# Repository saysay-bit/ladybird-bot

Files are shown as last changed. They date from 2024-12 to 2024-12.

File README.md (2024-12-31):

**Drawings**: Engineering drawings of individual parts

**Extra Components**: 3D models of extra components, e.g. spacers and nuts (not original)

**Main Parts**: 3D models of individual parts (.ipt)

**STL files**: 3D models of individual parts (.stl)

**LadybugBot Code.ino**: Full robot code for Arduino

**Robot Presentation Slides**: Presentation slides (for assessment) - can also be used as a summary

**robot.h**: Robot library

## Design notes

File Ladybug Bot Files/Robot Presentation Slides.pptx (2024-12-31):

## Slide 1

I Maze Solving Robot I
Ladybug Bot

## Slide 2

I Chassis Construction I
I Design & Creation I

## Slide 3

Design - Base

- Designed with the ladybug concept in mind
  - Large “body” section - ARB board, battery pack
  - Smaller “head” section - ball caster is mounted in direct centre
- Ultrasonic sensors
  - One at direct front, and one on each side
- Battery pack slots
  - Four rectangular slots in the centre
  - Battery pack stand slots in & out (keyhole)

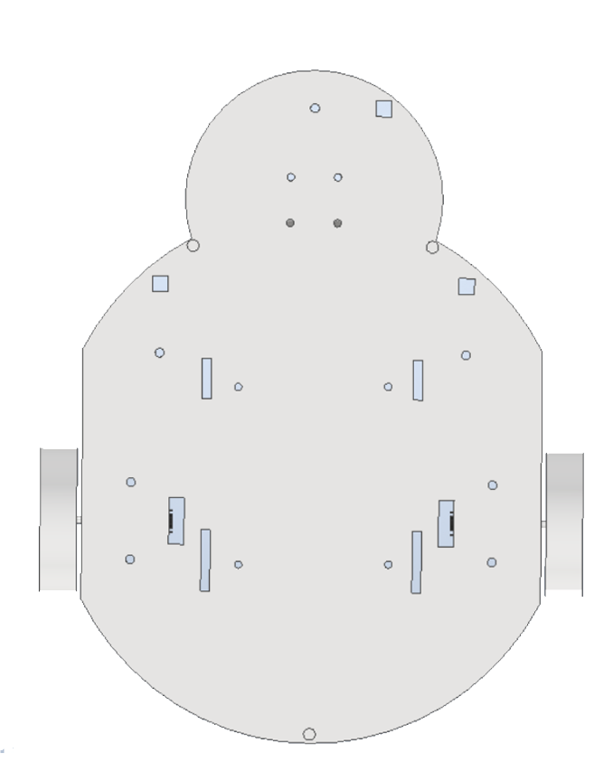
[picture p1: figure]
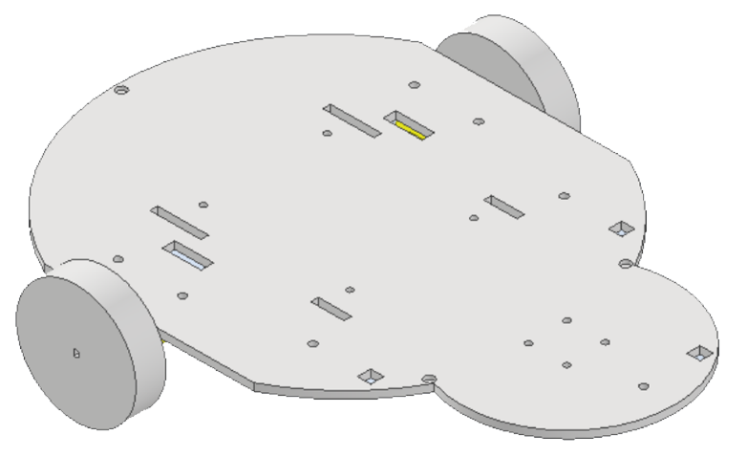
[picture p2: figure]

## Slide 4

Design - Battery Pack

- A stand that slots through the keyholes and rests above the ARB board.
- Small layer of foam to protect the battery pack and allow it to be removed in and out.
- Rounded slots on top to increase safety during use
- Printed in red to stick with the ladybug theme.

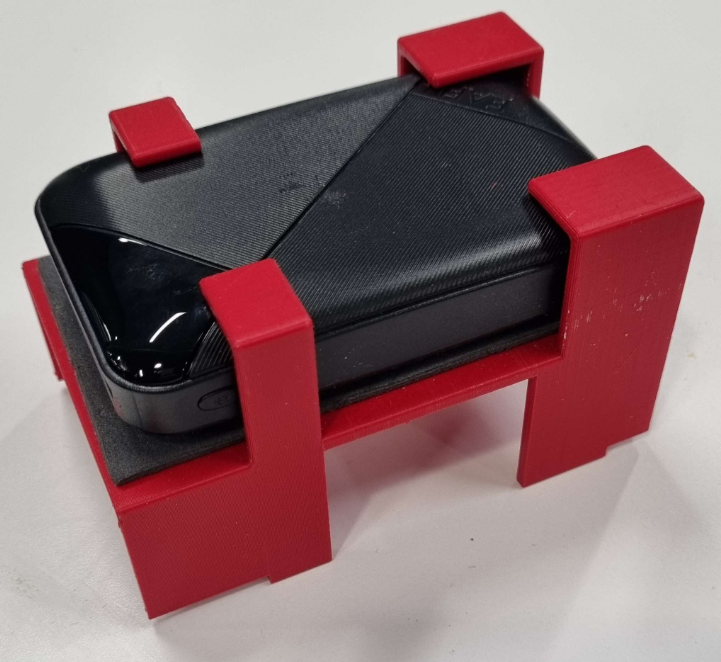
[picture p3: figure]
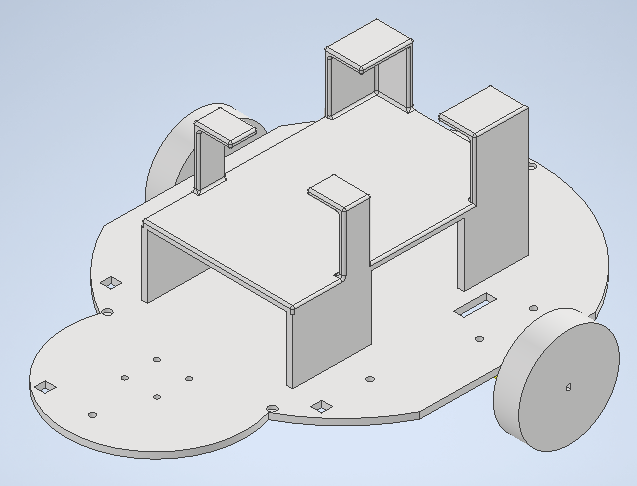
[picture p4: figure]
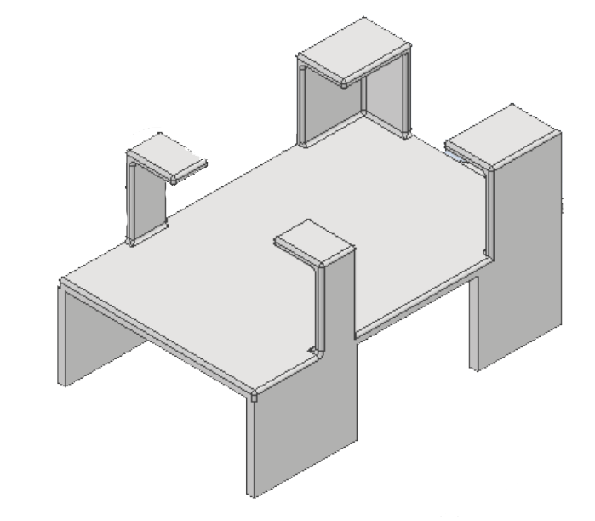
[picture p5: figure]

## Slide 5

Design - Cover

- Ladybug themed outer case, originally printed in black - spray painted red and small dots drawn on
- Magnetic holes on edges to stick neatly onto base
- Holes on sides and front to allow space for sensors
- Also doubles as protection for electronic parts
- Makes the Ladybug bot actually a ladybug!

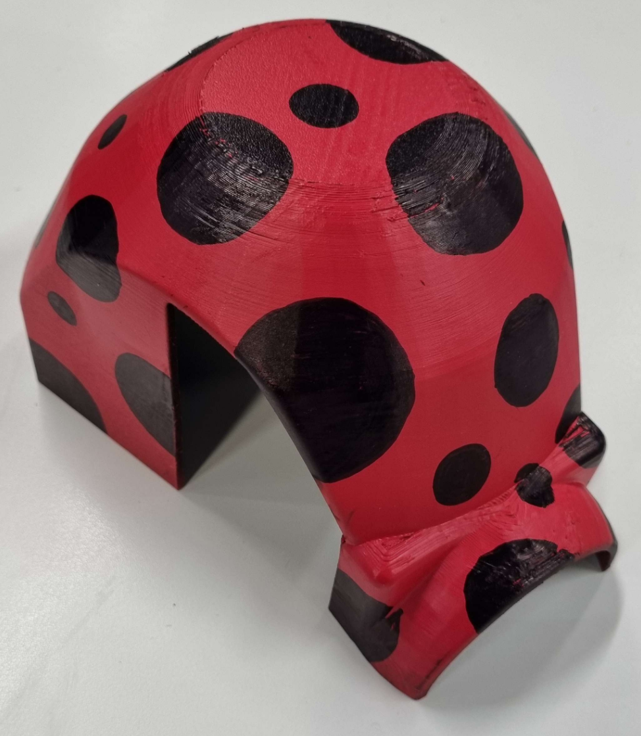
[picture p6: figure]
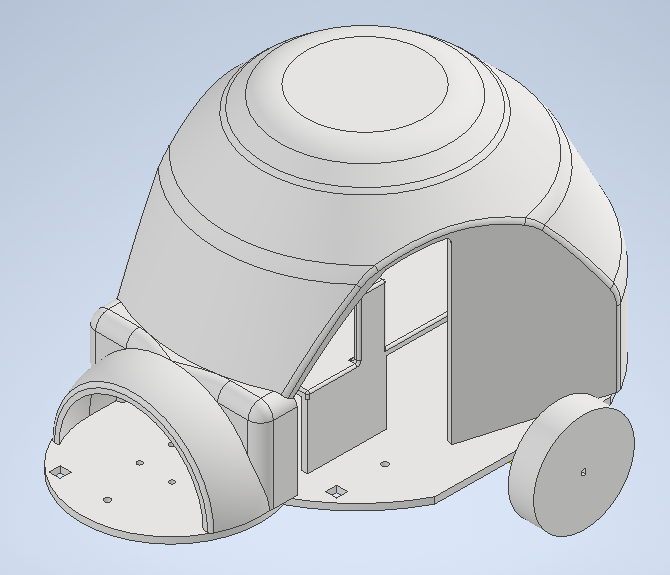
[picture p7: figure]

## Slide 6

I Obstacle Detection & Avoidance I
I Coding, Coordinates, Obstacles I

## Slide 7

Obstacle Detection - Sensors & Coordinates

- The Ladybug can sense obstacles around it using its ultrasonic sensors
- When the sensors detect something within <10 cm range:
  - Obstacle detected!
- Sensor readings are stored in a struct
- All sensors can be read at once and don’t need to be called individually!
- Once the obstacle is detected, the Ladybug can “map” it
- Coordinates of the obstacle are determined accordingly based on:
  - Distance to the obstacle, gathered from the sensors
  - Current location of the Ladybug

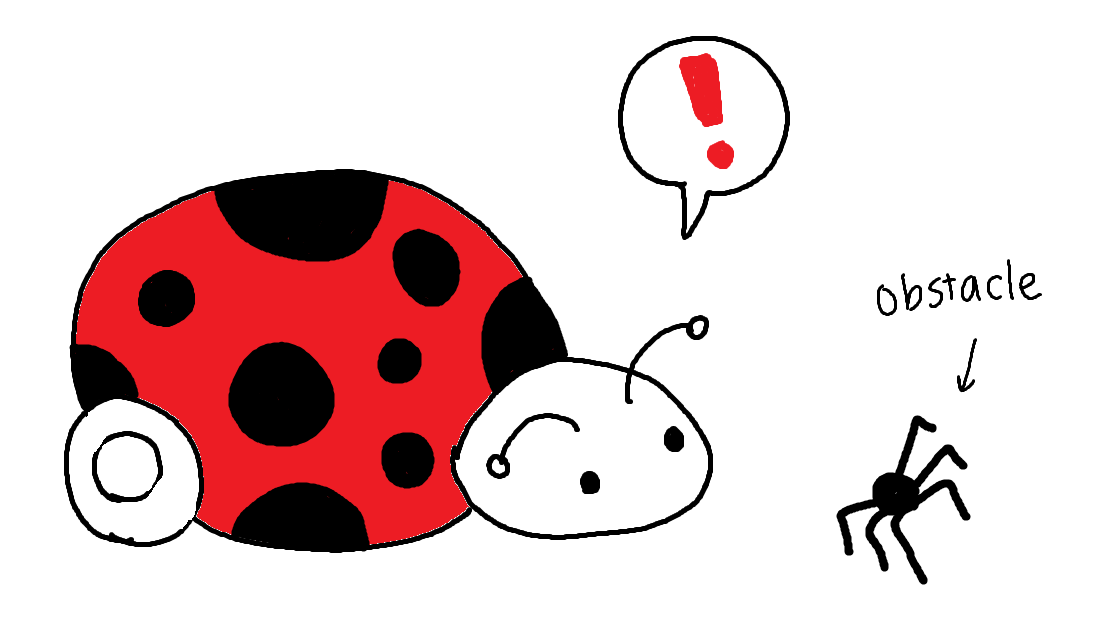
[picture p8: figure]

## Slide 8

Obstacle Detection - Movement

- The Ladybug can be programmed to avoid obstacles once detected!
- Forward/backward movement commands can be issued with two inputs:
  - Speed (in cm per second)
  - Target distance (in cm)
- The Ladybug will move at the input speed until the target distance is reached.
- Turn commands can be issued with two inputs:
  - Speed (in cm per second)
  - Target angle displacement (in degrees)
- All movements are set to a default speed of 8 cm/s
- Default turns are 90 degrees

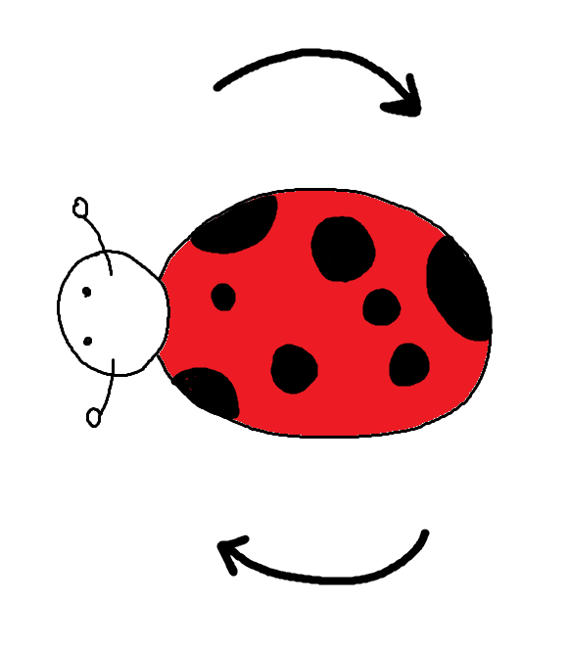
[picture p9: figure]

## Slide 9

I Maze Solutions I
I Shortest Path and Dijkstra’s Algorithm I

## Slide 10

Maze Solutions - Occupancy Grids

- The Ladybug creates an occupancy grid of the map that gets updated with obstacles as it moves.
- Each “cell” in the grid is 17cm x 17cm, and this creates a coordinate system.
- The occupancy grid is printed with (in testing):
  - Start (S)
  - Goal (G)
  - Path cells (*)
  - Obstacle (#)
  - Regular cells (.)
- But for simplicity is printed with 1s and 2s.

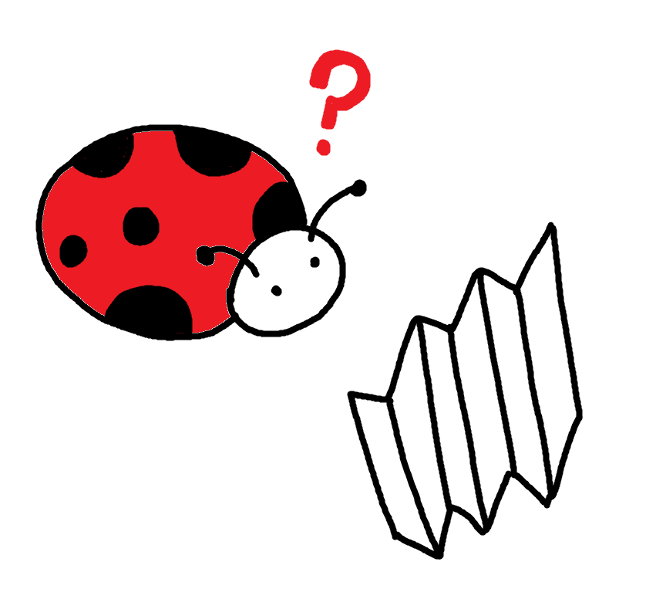
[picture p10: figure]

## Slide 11

Maze Solutions - Dijkstra’s Algorithm

- The Ladybug uses Dijkstra’s algorithm to compute the shortest path to the goal from the current point.
- As obstacles are mapped out, the new path is computed considering the obstacles.
- At the end, the Ladybug receives the shortest path to the goal as an array of coordinates.
- It also receives the length of the shortest path (in steps).
- In testing, the dijkstra() function can:
  - Print out a small map with the shortest path marked;
  - Print out the route as steps of coordinates.
- Once the ladybug receives the path:
  - It will attempt to follow each coordinate step by step.
  - Once the new coordinate is reached:
    - Obstacles are sensed and added onto the map.
    - Dijkstra runs again and returns a new path
    - Process repeats until goal is reached!

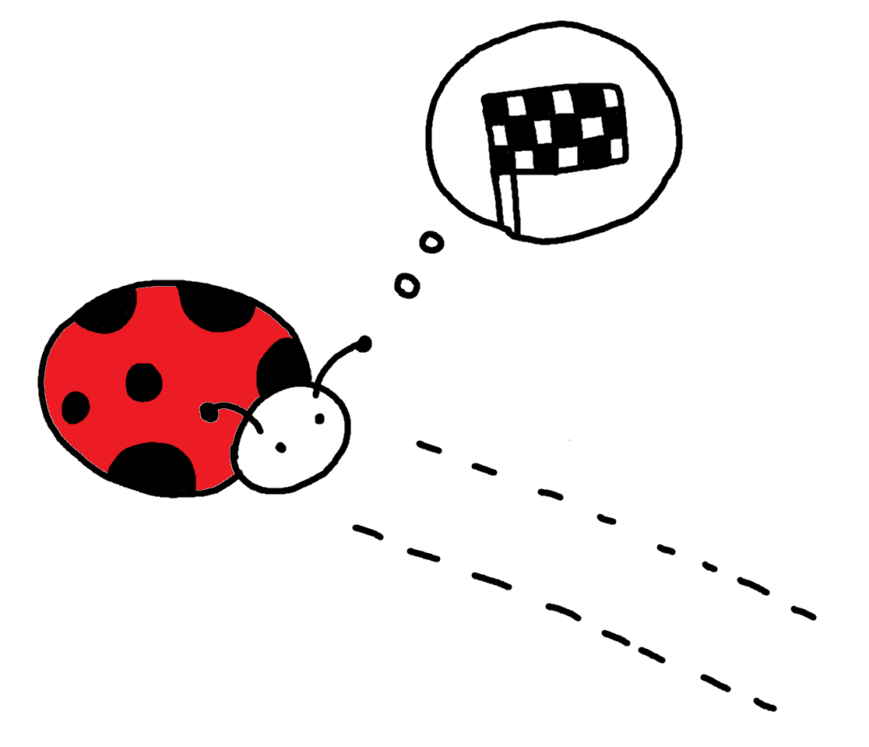
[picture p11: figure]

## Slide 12

Maze Solutions - Backtracking

- Once the goal is met, the Ladybug will reset its goal back to (0,0) - the start
- It will rerun the algorithms until it reaches its new goal - the start!
- The maze is then solved via Dijkstra’s!

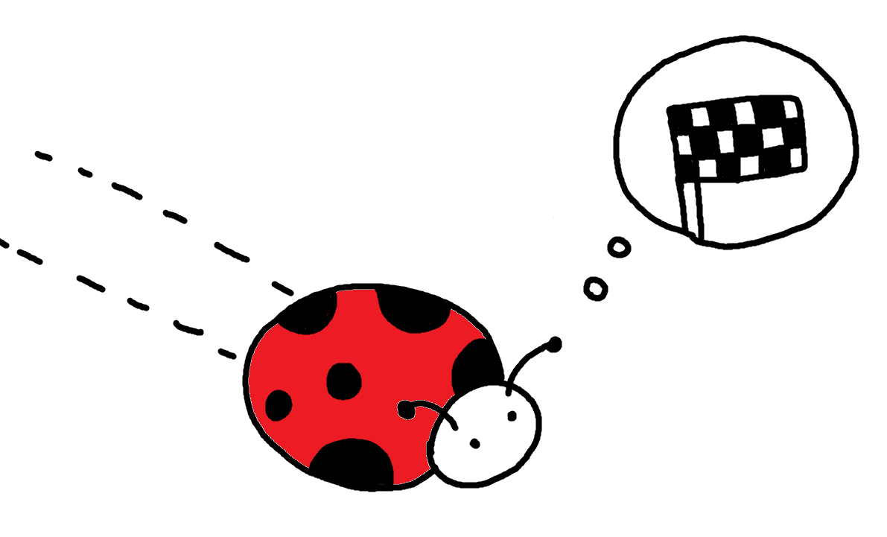
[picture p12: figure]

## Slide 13

I Bugsquashing I
I Problem Troubleshooting I

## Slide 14

Bug-squashing

- Bugs were fixed via repeated trial and error, and lots of print() statements!
- Threading was used to optimise angle & distance calculations
  - They depended on the encoders
  - Running them in tandem with everything else increased efficiency
- On initial submission, the Ladybug was able to find a path and update the map with obstacles, but struggled to follow the path properly.
  - This was (hopefully) fixed for the final presentation to ensure a smooth demonstration

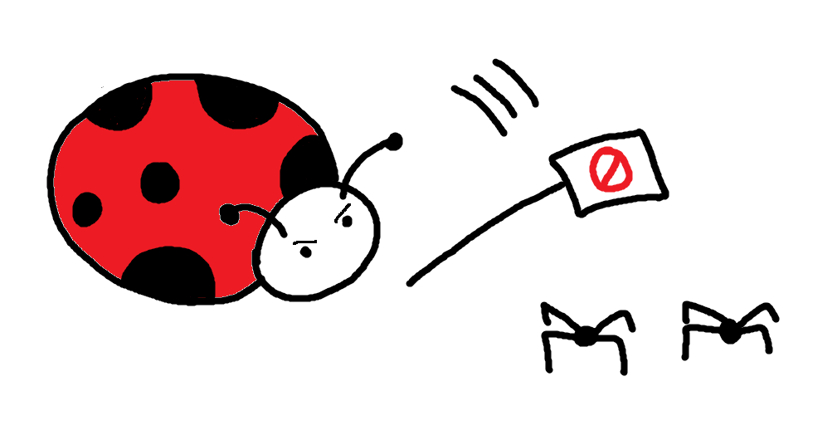
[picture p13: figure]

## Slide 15

I Improvements & Evaluation I
I What could’ve gone better? I

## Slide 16

I Thank you! I
I Any Questions? I

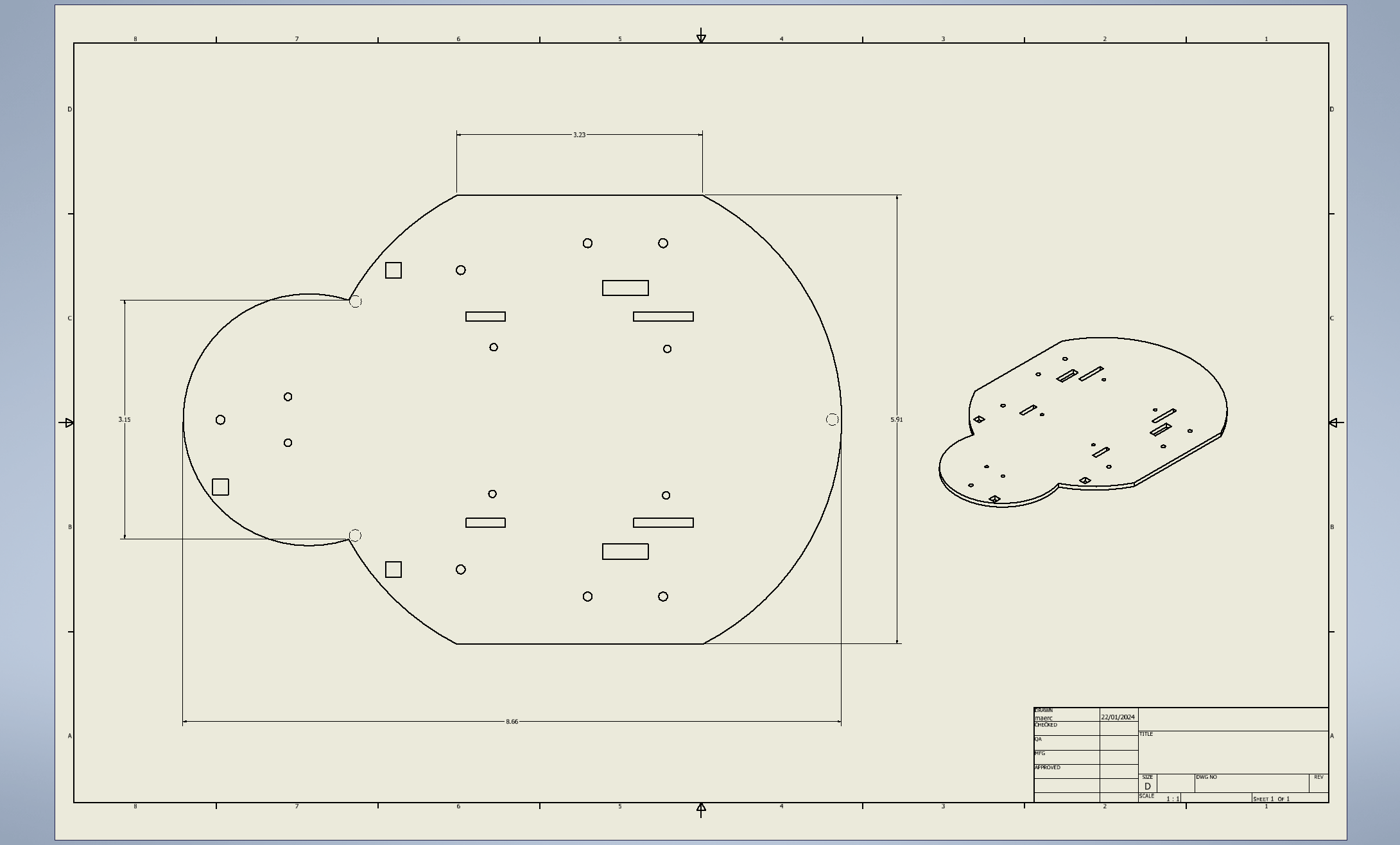
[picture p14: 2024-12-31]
Ladybug Bot Files/Drawings/Copy of Base Drawing.png

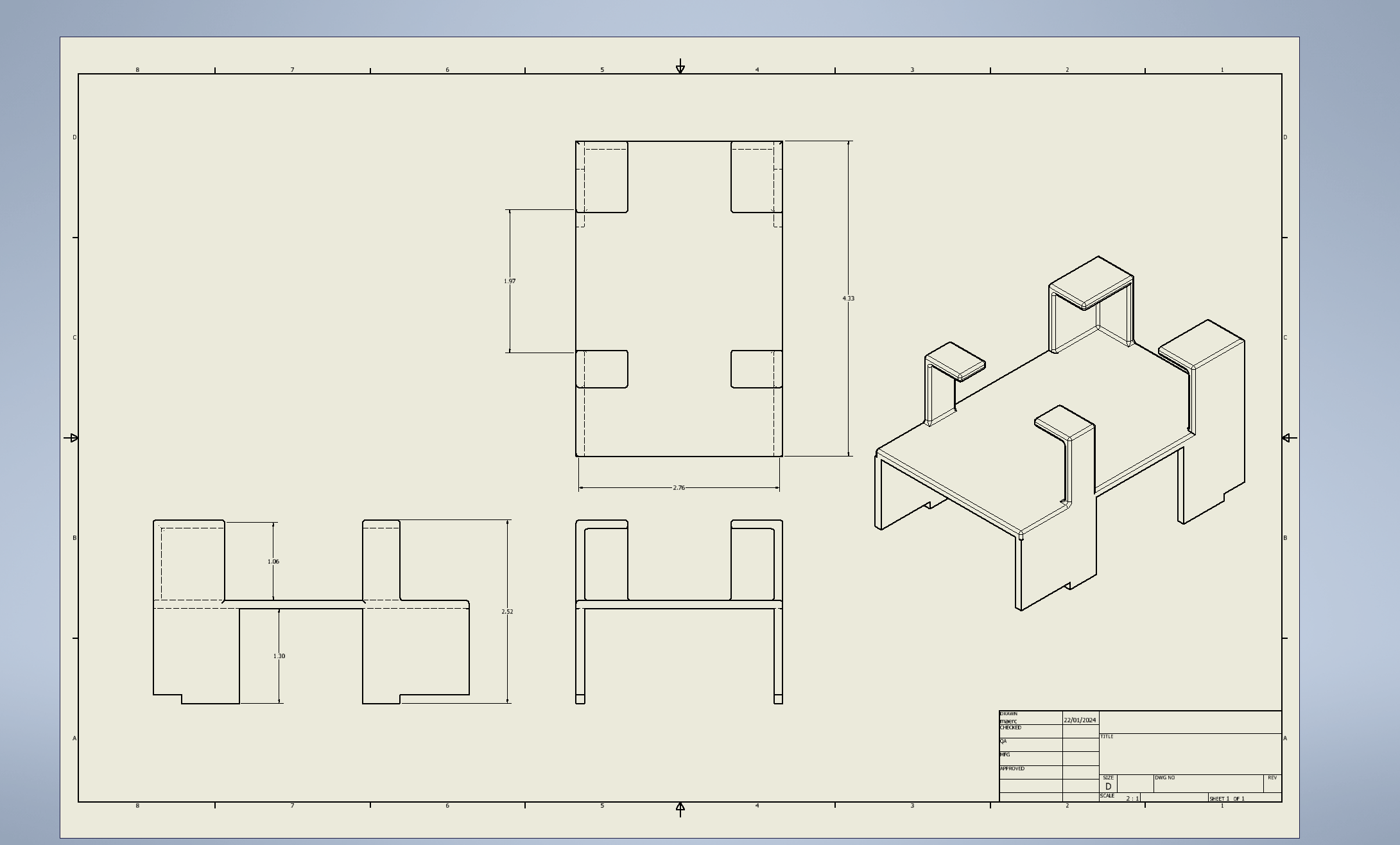
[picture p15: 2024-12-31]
Ladybug Bot Files/Drawings/Copy of Battery Holder Drawing.png

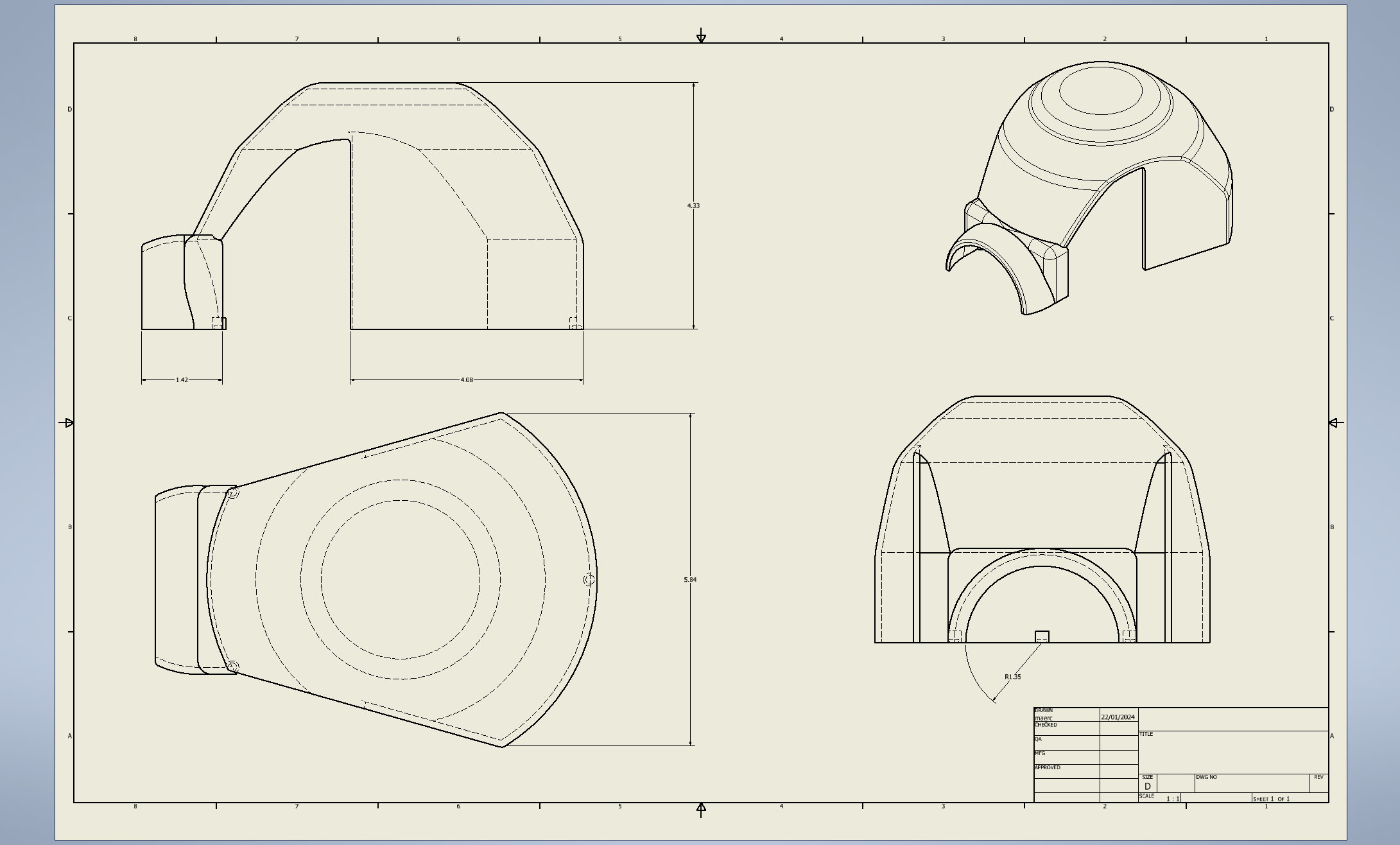
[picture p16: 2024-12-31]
Ladybug Bot Files/Drawings/Copy of Outer Cover Drawing.png

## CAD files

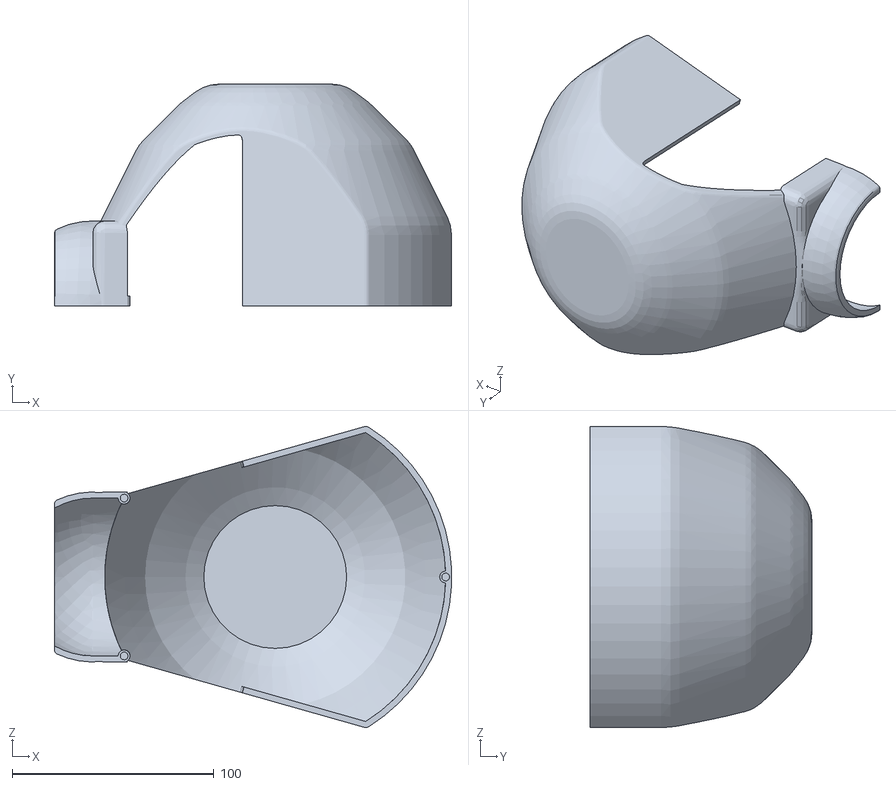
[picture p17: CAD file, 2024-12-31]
Ladybug Bot Files/STL files/BodyCover.stl
196.8 x 110.0 x 149.2

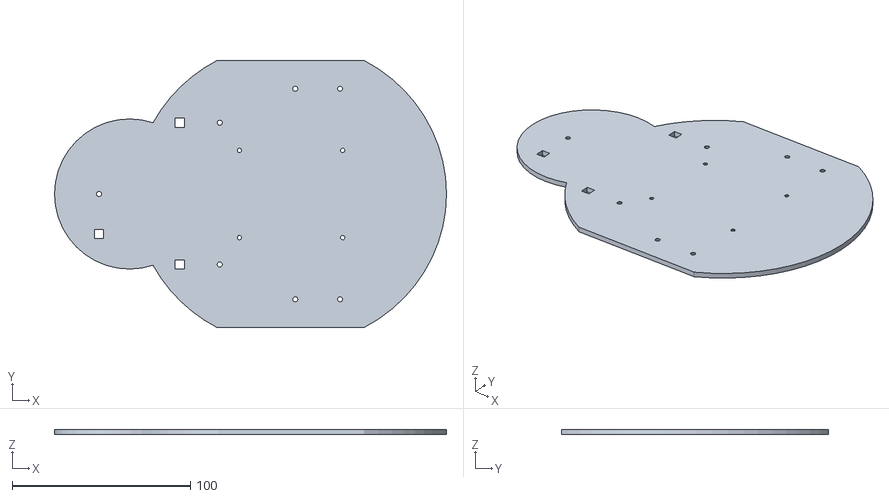
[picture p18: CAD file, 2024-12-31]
Ladybug Bot Files/STL files/Base.stl
220.0 x 150.1 x 3.00

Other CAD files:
Ladybug Bot Files/Extra Components (e.g. Spacers-Nuts)/Copy of 0.75in Ball Caster (Pololu).ipt
Ladybug Bot Files/Extra Components (e.g. Spacers-Nuts)/Copy of Caster Spacer 1,7mm.ipt
Ladybug Bot Files/Extra Components (e.g. Spacers-Nuts)/Copy of Caster Spacer 3,1mm.ipt
Ladybug Bot Files/Extra Components (e.g. Spacers-Nuts)/Copy of Caster Spacer 3mm.ipt
Ladybug Bot Files/Extra Components (e.g. Spacers-Nuts)/Copy of Caster Spacer 5mm.ipt
Ladybug Bot Files/Extra Components (e.g. Spacers-Nuts)/Copy of HC-SR04-UltrasonicSensor v7.ipt
Ladybug Bot Files/Extra Components (e.g. Spacers-Nuts)/Copy of M2.5 Hex Spacer 5mm.ipt
Ladybug Bot Files/Extra Components (e.g. Spacers-Nuts)/Copy of Motor Mount.ipt
Ladybug Bot Files/Extra Components (e.g. Spacers-Nuts)/Copy of MotorHolder.ipt
Ladybug Bot Files/Extra Components (e.g. Spacers-Nuts)/Copy of Motors Full Assembly.iam
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

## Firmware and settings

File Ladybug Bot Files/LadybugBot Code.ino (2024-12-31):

#include "mbed.h"
#include "robot.h"
using namespace rtos;
using namespace mbed;

#define PWM_PIN_A P0_27
#define PWM_PIN_B P1_2
#define DIR_PIN_A P0_4
#define DIR_PIN_B P0_5

#define ENC_PIN_A P1_11
#define ENC_PIN_B P1_12

#define SENSORLEFT_PIN 6   //P1_14 - SENSOR 2
#define SENSORFRONT_PIN 7  //P0_23 - SENSOR 1
#define SENSORRIGHT_PIN 4  //P1_15 - SENSOR 4

mbed::PwmOut MotorAPWM(P0_27);
mbed::PwmOut MotorBPWM(P1_2);

mbed::DigitalOut MotorADir(P0_4);
mbed::DigitalOut MotorBDir(P0_5);

Motor MotorA(PWM_PIN_A, DIR_PIN_A);
Motor MotorB(PWM_PIN_B, DIR_PIN_B);

UltrasonicSensor sensor_left(SENSORLEFT_PIN);
UltrasonicSensor sensor_front(SENSORFRONT_PIN);
UltrasonicSensor sensor_right(SENSORRIGHT_PIN);

float speedDefault = 8;
float distanceDefault = 10;
float turnDefault = 90;

int MovingCoords = 0;

int XMovement = 0;
int YMovement = 0;

int lastCoordsX = 0;
int lastCoordsY = 0;

int x_movement = 0;
int y_movement = 0;

char TargetFacing = 'U';
char Facing = 'U';

// Define grid dimensions
#define GRID_ROWS 12  //one grid box would be 17x17 cm
#define GRID_COLS 9
#define INT_MAX 100

// Define the occupancy grid
int MazeMap[GRID_ROWS][GRID_COLS] = {};

struct Cell {
  int CellX, CellY;
};

int CoordsX = 0;
int CoordsY = 0;

bool MovingDirection = true;

bool ObstacleLeft = false;
bool ObstacleRight = false;
bool ObstacleFront = false;

struct Cell start = { CoordsX, CoordsY };
struct Cell goal = { 4, 4 };

struct Cell path[GRID_ROWS * GRID_COLS];
int pathLength = 0;


//=======================================================================================================================================================================================
//State variables for localization: add each update and never set to 0
float angle = 90;  //0 is along the x-axis (unit circle)
float positionX = 0;
float positionY = 0;

Thread angleChecking;

//Sensor Readings structure and function===================================================================================================================================================
struct SensorReadings {  //group related data items under a single name
  float distance_left;
  float distance_front;
  float distance_right;
};


SensorReadings readAllSensors() {  //returns an instance of SensorReadings structure
  SensorReadings readings;
  readings.distance_left = sensor_left.DistanceMeasurement();
  readings.distance_front = sensor_front.DistanceMeasurement();
  readings.distance_right = sensor_right.DistanceMeasurement();

  return readings;
}



//Robot current state: updated by state functions ===============================================================================================================================
enum robotState { stopState = 0,
                  forwardState,
                  leftState,
                  rightState,
                  backState,
                  defaultState
} behaviour;


//===============================================================================================================================================================================
//Behavior variables: updated in each loop but only reset once behavior finishes (e.g. move x cm)
float distanceMoved = 0.0;
float angleMoved = 0.0;

float distanceRTotal = 0.0;
float distanceLTotal = 0.0;

//angle fixing to 90 ================================================================================================================================================


bool ActionComplete = false;

//moving forward/backward/turning ================================================================================================================================================
void move(float speedIn, float targetDistance, bool moveBack) {
  angleChecking.start(callback(anglesAndCoordsUpdate));

  updateMazeMapObstacles();


  //positionFixing.start(callback(fix_position));

  ActionComplete = false;

  float speedOut = (speedIn + 3) / 40;

  MotorAPWM.write(speedOut);
  MotorBPWM.write(speedOut);
  MotorADir = moveBack ? 0 : 1;
  MotorBDir = moveBack ? 1 : 0;


  float tolerance = 1;  //note distances to actual distances are 1cm off, but tolerance is low to avoid error

  //ISSUE WITH MOVEMENT ADDING 2 TO COORDS SEEMS TO BE HERE, FIXED BY CHECKING COORDINATE NOT DISTANCE

  static float initialDistance = ((std::fabs(distanceRTotal) + std::fabs(distanceLTotal)) * 0.5);
  float currentDistance = ((std::fabs(distanceRTotal) + std::fabs(distanceLTotal)) * 0.5);

  float adjusted_targetDistance = (moveBack ? -targetDistance : targetDistance);
  if (MovingCoords == 1) {
    if (Facing == 'L' || Facing == 'R') {
      if (CoordsX == XMovement) {
        stop();
        ActionComplete = true;
        Serial.println("Distance Met!");
        initialDistance = (std::fabs(distanceRTotal) + std::fabs(distanceLTotal)) / 2;
      }
    } else {
      if (Facing == 'F' || Facing == 'B') {
        if (CoordsY == YMovement) {
          stop();
          ActionComplete = true;
          Serial.println("Distance Met!");
          initialDistance = (std::fabs(distanceRTotal) + std::fabs(distanceLTotal)) / 2;
        }
      } else {
        Serial.println("Unknown Movement Direction!");
      }
    }
  } else {
    if ((std::fabs(initialDistance - currentDistance + adjusted_targetDistance)) <= tolerance) {
      stop();
      ActionComplete = true;
      Serial.println("Distance Met!");
      initialDistance = (std::fabs(distanceRTotal) + std::fabs(distanceLTotal)) / 2;
    }
  }
}


void move_forward(float speedIn, float targetDistance) {
  while (ActionComplete == false) {
    move(speedIn, targetDistance, false);
  }
}

void move_backward(float speedIn, float targetDistance) {
  while (ActionComplete == false) {

    move(speedIn, targetDistance, true);
  }
}

void testing_function() {
  static int testState = 0;

  switch (testState) {
    case 0:
      moveToCoords(2, 2);
      break;
  }
}

void stop() {
  MotorAPWM.write(0);
  MotorBPWM.write(0);
}

static float initialAngle = angle;
static int fullRotations = 0;
float prevDeltaX = 0;
float prevDeltaY = 0;
float cumulativeX = 0;
float cumulativeY = 0;

void turn(float speedIn, float targetAngle, bool turnRight) {
  //Serial.println("Turning");
  angleChecking.start(callback(anglesAndCoordsUpdate));
  ActionComplete = false;

  static float initialAngle = angle;

  float speedOut = (speedIn + 3) / 40;
  MotorAPWM.write(speedOut);
  MotorBPWM.write(speedOut);
  MotorADir = turnRight ? 0 : 1;
  MotorBDir = turnRight ? 0 : 1;

  float tolerance = 1.0;

  if (turnRight) {  //math for turning right
    if (initialAngle < -270) {
      if (std::fabs(angle - 360.0f - initialAngle + targetAngle) <= tolerance) {
        //behaviour = forwardState; //change to stop for testing
        stop();
        angleMoved = 0;
        initialAngle = angle;
        ActionComplete = true;
        wait_us(1000);
      }
    } else {
      if (std::fabs(angle - 0 - initialAngle + targetAngle) <= tolerance) {  //fullRotations to 0
        //behaviour = forwardState; //change to stop for testing
        stop();
        angleMoved = 0;
        initialAngle = angle;
        ActionComplete = true;
        wait_us(1000);
      }
    }
  } else {  //math for turning left
    if (initialAngle > 270) {
      if (std::fabs(angle + 360.0f - initialAngle - targetAngle) <= tolerance) {
        //behaviour = forwardState; //change to stop for testing
        stop();
        angleMoved = 0;
        initialAngle = angle;
        ActionComplete = true;
        wait_us(1000);
      }
    } else {
      if (std::fabs(angle + 0 - initialAngle - targetAngle) <= tolerance) {  //fullRotations to 0
        //behaviour = forwardState; //change to stop for testing
        stop();
        angleMoved = 0;
        initialAngle = angle;
        ActionComplete = true;
        wait_us(1000);
      }
    }
  }


  wait_us(10000);  // Adjust the delay as needed
}

void turn_right(float speedIn, float targetAngle) {
  Serial.println("Turning Right");
  while (ActionComplete == false) {
    turn(speedIn, targetAngle, true);
  }
}


void turn_left(float speedIn, float targetAngle) {
  Serial.println("Turning Left");
  while (ActionComplete == false) {
    turn(speedIn, targetAngle, false);
  }
}


//defining interrupts and timers to count encoders===========================================================================================================================
mbed::InterruptIn EncoderR(P1_11);
mbed::InterruptIn EncoderL(P1_12);

long int WheelRevR;
long int WheelRevL;

long int PulseCountR;
long int PulseCountL;

mbed::Timer timeCheck;



//encoder count read functions =======================================================================================================================================================
void countEncoderR() {
  PulseCountR++;  //encoder count increases on every rising edge (0 to 1)

  if (PulseCountR % 6 == 0) {      //checks if one rotation has completed (6 counts per rotation)
    if (PulseCountR % 100 == 0) {  //increases Shaft Revolutions every 100 counts
      WheelRevR++;
    }
  }
}

void countEncoderL() {
  PulseCountL++;  //encoder count increases on every rising edge (0 to 1)

  if (PulseCountL % 6 == 0) {      //checks if one rotation has completed (6 counts per rotation)
    if (PulseCountL % 100 == 0) {  //increases Shaft Revolutions every 100 counts
      WheelRevL++;
    }
  }
}


//Map stuff =========================================================================================================================================================================
void printMazeMap() {
  for (int i = 0; i < GRID_ROWS; i++) {
    for (int j = 0; j < GRID_COLS; j++) {
      Serial.print(MazeMap[i][j]);
      Serial.print(" ");
    }
    Serial.println();
  }
}

void initialiseMazeMap() {
  for (int i = 0; i < GRID_ROWS; ++i) {
    for (int j = 0; j < GRID_COLS; ++j) {
      MazeMap[i][j] = 1;
    }
  }
}

int ObstacleX;
int ObstacleY;


void ObstacleMapping() {
  CoordsX = CoordsX;
  CoordsY = CoordsY;
  findFacing();

  Serial.println(Facing);
  SensorReadings currentReadings = readAllSensors();

  if (ObstacleLeft == true) {
    if (Facing == 'F') {
      Serial.println("Facing F");
      ObstacleX = CoordsX - 1;
      ObstacleY = CoordsY;
      MazeMap[ObstacleX][ObstacleY] = 2;

    } else if (Facing == 'B') {
      Serial.println("Facing B");
      ObstacleX = CoordsX + 1;
      ObstacleY = CoordsY;
      MazeMap[ObstacleX][ObstacleY] = 2;

    } else if (Facing == 'R') {
      Serial.println("Facing R");
      ObstacleX = CoordsX;
      ObstacleY = CoordsY + 1;
      MazeMap[ObstacleX][ObstacleY] = 2;

    } else if (Facing == 'L') {
      Serial.println("Facing L");
      ObstacleX = CoordsX;
      ObstacleY = CoordsY - 1;
      MazeMap[ObstacleX][ObstacleY] = 2;
    }
    Serial.print("CoordsX: ");
    Serial.println(CoordsX);
    Serial.print("CoordsY: ");
    Serial.println(CoordsY);
    Serial.println("Obstacle to the left`!");
    Serial.print("Obstacle X: ");
    Serial.println(ObstacleX);
    Serial.print("Obstacle Y: ");
    Serial.println(ObstacleY);

    ObstacleLeft = false;
  }
  if (ObstacleRight == true) {
    if (Facing == 'F') {
      Serial.println("Facing F");
      ObstacleX = CoordsX + 1;
      ObstacleY = CoordsY;
      MazeMap[ObstacleX][ObstacleY] = 2;

    } else if (Facing == 'B') {
      Serial.println("Facing B");
      ObstacleX = CoordsX - 1;
      ObstacleY = CoordsY;
      MazeMap[ObstacleX][ObstacleY] = 2;

    } else if (Facing == 'R') {
      Serial.println("Facing R");
      ObstacleX = CoordsX;
      ObstacleY = CoordsY - 1;
      MazeMap[ObstacleX][ObstacleY] = 2;

    } else if (Facing == 'L') {
      Serial.println("Facing L");
      ObstacleX = CoordsX;
      ObstacleY = CoordsY + 1;
      MazeMap[ObstacleX][ObstacleY] = 2;
    }

    Serial.print("CoordsX: ");
    Serial.println(CoordsX);
    Serial.print("CoordsY: ");
    Serial.println(CoordsY);
    Serial.println("Obstacle to the right!");
    Serial.print("Obstacle X: ");
    Serial.println(ObstacleX);
    Serial.print("Obstacle Y: ");
    Serial.println(ObstacleY);
    ObstacleRight = false;
  }
  if (ObstacleFront == true) {
    if (Facing == 'F') {
      Serial.println("Facing F");
      ObstacleX = CoordsX;
      ObstacleY = CoordsY + 1;
      MazeMap[ObstacleX][ObstacleY] = 2;

    } else if (Facing == 'B') {
      Serial.println("Facing B");
      ObstacleX = CoordsX;
      ObstacleY = CoordsY - 1;
      MazeMap[ObstacleX][ObstacleY] = 2;

    } else if (Facing == 'R') {

      Serial.println("Facing R");
      ObstacleX = CoordsX + 1;
      ObstacleY = CoordsY;
      MazeMap[ObstacleX][ObstacleY] = 2;

    } else if (Facing == 'L') {
      Serial.println("Facing L");
      ObstacleX = CoordsX - 1;
      ObstacleY = CoordsY;
      MazeMap[ObstacleX][ObstacleY] = 2;
    }
    ObstacleFront = false;
    Serial.print("CoordsX: ");
    Serial.println(CoordsX);
    Serial.print("CoordsY: ");
    Serial.println(CoordsY);
    Serial.println("Obstacle ahead!");
    Serial.print("Obstacle X: ");
    Serial.println(ObstacleX);
    Serial.print("Obstacle Y: ");
    Serial.println(ObstacleY);
  }
}

void updateMazeMapObstacles() {
  angleChecking.start(callback(anglesAndCoordsUpdate));
  SensorReadings currentReadings = readAllSensors();
  if (currentReadings.distance_left < 8 && currentReadings.distance_left > 0) {

    ObstacleLeft = true;
    Serial.println("OBSTACLE LEFT");
  }

  if (currentReadings.distance_right < 8 && currentReadings.distance_right > 0) {

    ObstacleRight = true;
    Serial.println("OBSTACLE RIGHT");
  }

  if (currentReadings.distance_front < 8 && currentReadings.distance_front > 0) {

    ObstacleFront = true;
    Serial.println("OBSTACLE FRONT");
  }

  //MazeMap[ObstacleX][ObstacleY] = 2;  //assigns the grid with these coordinates with a 1
  dijkstra(MazeMap, start, goal);
  Serial.println("Occupancy Grid:");
  printMazeMap();
}

//Dijkstra stuff ===================================================================================================================================================================================

int isValid(int row, int col) {
  return (row >= 0) && (row < GRID_ROWS) && (col >= 0) && (col < GRID_COLS);
}

int min(int a, int b) {
  return (a < b) ? a : b;
}

int dijkstra(int maze[GRID_ROWS][GRID_COLS], struct Cell begin, struct Cell goal) {
  begin = { CoordsX, CoordsY };

  angleChecking.start(callback(anglesAndCoordsUpdate));
  pathLength = 0;  // Reset pathLength

  // defining stuff
  int distances[GRID_ROWS][GRID_COLS];
  int visited[GRID_ROWS][GRID_COLS];
  struct Cell predecessors[GRID_ROWS][GRID_COLS];

  for (int i = 0; i < GRID_ROWS; i++) {
    for (int j = 0; j < GRID_COLS; j++) {
      distances[i][j] = INT_MAX;
      visited[i][j] = 0;
      predecessors[i][j] = { -1, -1 };
    }
  }

  distances[start.CellX][start.CellY] = 0;

  for (int count = 0; count < GRID_ROWS * GRID_COLS; count++) {
    int minDistance = INT_MAX;
    int minRow;
    int minCol;

    for (int i = 0; i < GRID_ROWS; i++) {
      for (int j = 0; j < GRID_COLS; j++) {
        if (!visited[i][j] && distances[i][j] < minDistance) {
          minDistance = distances[i][j];
          minRow = i;
          minCol = j;
        }
      }
    }

    visited[minRow][minCol] = 1;

    for (int i = -1; i <= 1; i++) {
      for (int j = -1; j <= 1; j++) {
        if ((i == 0 || j == 0) && !(i == 0 && j == 0)) {
          int newRow = minRow + i;
          int newCol = minCol + j;

          if (isValid(newRow, newCol) && maze[newRow][newCol] != 2 && !visited[newRow][newCol] && distances[minRow][minCol] != INT_MAX) {
            int newDistance = distances[minRow][minCol] + maze[newRow][newCol];

            if (newDistance < distances[newRow][newCol]) {
              distances[newRow][newCol] = newDistance;
              predecessors[newRow][newCol] = (struct Cell){
                minRow, minCol
              };
            }
          }
        }
      }
    }

    if (minRow == goal.CellX && minCol == goal.CellY) {
      /*
        Serial.println("Maze with marked path: ");
        for (int i = 0; i < GRID_ROWS; i++) {
        for (int j = 0; j < GRID_COLS; j++) {

          if (maze[i][j] == 1) {  //if explored
            if (i == start.CellX && j == start.CellY) {
              Serial.print("S ");
            } else if (i == goal.CellX && j == goal.CellY) {
              Serial.print("G ");
              /*
                } else if (predecessors[i][j].CellX != -1 || predecessors[i][j].CellY != -1) {  //explored
                Serial.print("* ");

            } else {
              bool isPathCell = false;
              // Check if the current cell is in the path
              for (int k = 0; k < pathLength; k++) {
                if (i == path[k].CellX && j == path[k].CellY) {
                  isPathCell = true;
                  break;
                }
              }
              if (isPathCell) {
                Serial.print("@ ");
              } else {
                Serial.print(". ");
              }
            }

          } else {
            Serial.print("# ");
          }
        }
        Serial.println();
        }
        Serial.println();
      */
      //    if (minRow == goal.CellX && minCol == goal.CellY) {
      Serial.print("Shortest distance from start to goal: ");
      Serial.println(distances[goal.CellX][goal.CellY]);

      Serial.println("Shortest path:");

      struct Cell currentCell = goal;

      while (!(currentCell.CellX == start.CellX && currentCell.CellY == start.CellY)) {
        path[pathLength++] = currentCell;
        currentCell = predecessors[currentCell.CellX][currentCell.CellY];
      }

      // Print the path in reverse order
      for (int i = pathLength; i >= 0; i--) {
        Serial.print("(");
        Serial.print(path[i].CellX);
        Serial.print(", ");
        Serial.print(path[i].CellY);
        Serial.print(") -> ");
      }

      Serial.print("Path Length: ");
      Serial.println(pathLength);

      // Reverse path order
      for (int i = 0; i < pathLength / 2; i++) {
        struct Cell temp = path[i];
        path[i] = path[pathLength - 1 - i];
        path[pathLength - 1 - i] = temp;
      }

      return pathLength;
    }
  }
  // If the goal is unreachable
  Serial.println("Goal is unreachable!");
  return 0;
}


void waitForActionCompletion() {
  // Wait for ActionComplete to become true
  while (!ActionComplete) {
    wait_us(1000);  // You can optionally add a delay here to avoid busy-waiting
  }
  // Reset ActionComplete for the next action
  ActionComplete = false;
}
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
void loop() {

  angleChecking.start(callback(anglesAndCoordsUpdate));
  //positionFixing.start(callback(fix_position));

  RobotMoveUpdateDijkstraMove();
  //moveToCoords(2, 2);
  //anglesAndCoordsUpdate();

  //setting period of motors =======================================================================================================================================================
  MotorAPWM.period_us(20);  //10us = 100kHz, 20us = 50kHz
  //MotorAPWM.write(0.2f); //duty cycle. 0% doesn't move motor, 100% is full speed

  MotorBPWM.period_us(20);
  //MotorBPWM.write(0.2f);

  //reading direction inputs =======================================================================================================================================================
  if (Serial.available() > 0) {
    char movement = Serial.read();
    switch (movement) {
      case ' ':
        behaviour = stopState;
        break;

      case 'w':
        behaviour = forwardState;
        break;

      case 'a':
        behaviour = leftState;
        break;

      case 's':
        behaviour = backState;
        break;

      case 'd':
        behaviour = rightState;
        break;

      case 'q':
        behaviour = defaultState;
        break;
    }
  }


  //changes movement based on the state (default things) ===========================================================================================================================
  switch (behaviour) {  //does them all at the same time it seems
    case forwardState:  //continuously moving forward
      //Serial.println("Executing forwardState");
      move_forward(speedDefault, distanceDefault);
      /*
        MotorAPWM.write(0.275);
        MotorBPWM.write(0.275);

        MotorADir = 1;
        MotorBDir = 0;
      */
      //updateMazeMapObstacles();
      //fix_position(speedDefault);  // Call fix_position continuously
      break;

    case leftState:  //continuously turning left

      //Serial.println("Executing leftState");
      turn_left(speedDefault, turnDefault);
      break;

    case rightState:
      //Serial.println("Executing rightState");
      turn_right(speedDefault, turnDefault);
      break;

    case backState:  //continuously moving backwards
      //Serial.println("Executing backState");

      MotorAPWM.write(0.275);
      MotorBPWM.write(0.275);

      MotorADir = 0;
      MotorBDir = 1;

      //move_backward(speedDefault, distanceDefault);
      break;

    case stopState:
      //Serial.println("Executing stopState");
      MotorAPWM.write(0);
      MotorBPWM.write(0);
      break;

    case defaultState:
      Serial.println("Executing DefaultState");
      testing_function();
      //CoordsChangeUpdateCall();
      //updateMazeMapObstacles();
      //RobotMoveUpdateDijkstraMove();
      //wait_us(1000000);
      break;

    default:
      Serial.println("Unknown behaviour");
  }

  wait_us(1000);
}

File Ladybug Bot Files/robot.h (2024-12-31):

//Header file for RDaC

#define GRID_ROWS 12  //one grid box would be 5x5 cm
#define GRID_COLS 9
#define INT_MAX 100

//Ultrasonic sensor class creation =======================================================================
class UltrasonicSensor {
  private:
    int pin;
    unsigned long startTime;
    unsigned long endTime;

  public:
    //Constructor
    UltrasonicSensor(int pinNum) : pin(pinNum) {}

    //function to measure distance
    float DistanceMeasurement() {
      
      //Send the trigger pulse
        pinMode(pin, OUTPUT);
        digitalWrite(pin, LOW);
        delayMicroseconds(2);
        digitalWrite(pin, HIGH);
        delayMicroseconds(10);
        digitalWrite(pin, LOW);

      //Switch to input to listen for echo
        pinMode(pin, INPUT);

      //Measure the duration of the echo signal
        unsigned long duration = pulseIn(pin, HIGH, 25000);  // 25ms timeout
      /*
        Serial.print("Sensor Duration ");
        Serial.print(pin);
        Serial.print(": ");
        Serial.println(duration);


      if (duration == 0) {
        Serial.println("pulseIn timed out!");
      }
      */
      float distance = duration * 0.0343 / 2;
      return distance;
    }
};

class Motor {
  private:
    PinName PWM_Pin;
    PinName DIR_Pin;

  public:
    //Constructor
    Motor(PinName pwmPin, PinName dirPin) : PWM_Pin(pwmPin), DIR_Pin(dirPin) {}

};


float closest90Fix(float angle_to_fix);
void fix_position();

void stop();

void move_forward(float speedIn, float targetDistance);
void move_backward(float speedIn, float targetDistance);

void turn(float speedIn, float targetAngle, bool turnRight);


void turn_right(float speedIn, float targetAngle);
void turn_left(float speedIn, float targetAngle);

void countEncoderR();
void countEncoderL();

float calculate_deltaDelta();

void updateMazeMapObstacles();

void anglesAndCoordsUpdate();

int dijkstra(int maze[GRID_ROWS][GRID_COLS], struct Cell begin, struct Cell goal);
